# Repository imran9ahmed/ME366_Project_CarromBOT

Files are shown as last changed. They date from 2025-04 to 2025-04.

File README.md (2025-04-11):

# 🤖 Project Carrom Bot

## 📄 Abstract
An Arduino-based electro-mechanical robotic system designed to **automate the sorting of carrom pucks** using a **4-DOF robotic arm mounted on a mobile cart** with suction mechanism. The robot successfully demonstrates accurate puck picking and placement through pre-programmed logic. It showcases how low-cost electro-mechanical integration can be applied in precision automation tasks, with potential for scaling to industrial sorting systems.

> 🚀 Developed as part of the course [ME366: Electro-Mechanical System Design and Practice] at **Bangladesh University of Engineering and Technology (BUET)**.

---

## 📽️ Project Demonstrations

- 🎯 **Complete Project Demonstration**: [Watch on YouTube](https://www.youtube.com/watch?v=0QuMNoEQiSg)
- 🧲 **Suction Mechanism Tutorial**: [Watch Tutorial](https://www.youtube.com/watch?v=8Wvk7AqxIFw)

---

## 🧠 Objective

To design and implement a robotic system capable of autonomously arranging carrom discs into pre-programmed patterns with high accuracy and repeatability.

---

## 🛠️ Components Used

- Arduino Uno
- MG996R 10kg Servo Motors (×4)
- Nema-17 Stepper Motors (×2)
- DRV8825 Stepper Motor Driver
- L298N Motor Driver
- 12V DC Vacuum Pump
- Suction Cup with Vulcanized Rubber Tip
- Jumper & Electrical Wires
- DC-DC Buck Converter (LM2596)
- 85mm Plastic Wheels
- Custom Wooden and 3D Printed Chassis

---

## 🧩 How It Works

1. Stepper motor moves the bot to the center of the carrom board.
2. Servo motors manipulate the robotic arm to reach a disc.
3. Vacuum pump turns ON to pick up the disc.
4. The arm carries the disc to the target position.
5. Vacuum turns OFF to release it.
6. The bot moves backward to start the next sequence.
7. Repeats the process for all discs.

---

## 🧪 Methodology

- **CAD Design**: SolidWorks for modeling the cart and arm.
- **Fabrication**: Lightweight wooden body and polymer arms (3D printed).
- **Control**: Arduino IDE with pre-programmed sequences for each disc.
- **Motion**: 
  - Stepper motors drive the wheels (for mobility).
  - Servo motors control arm segments (for picking & placing).
  - Vacuum pump uses DC motor to hold discs during transport.

---

## 📊 Results

The robot successfully completed the task of picking and placing all carrom discs in the desired pattern during a live demonstration. The suction mechanism was robust, and servo positioning was accurate.

---

## 🖼️ Project Poster

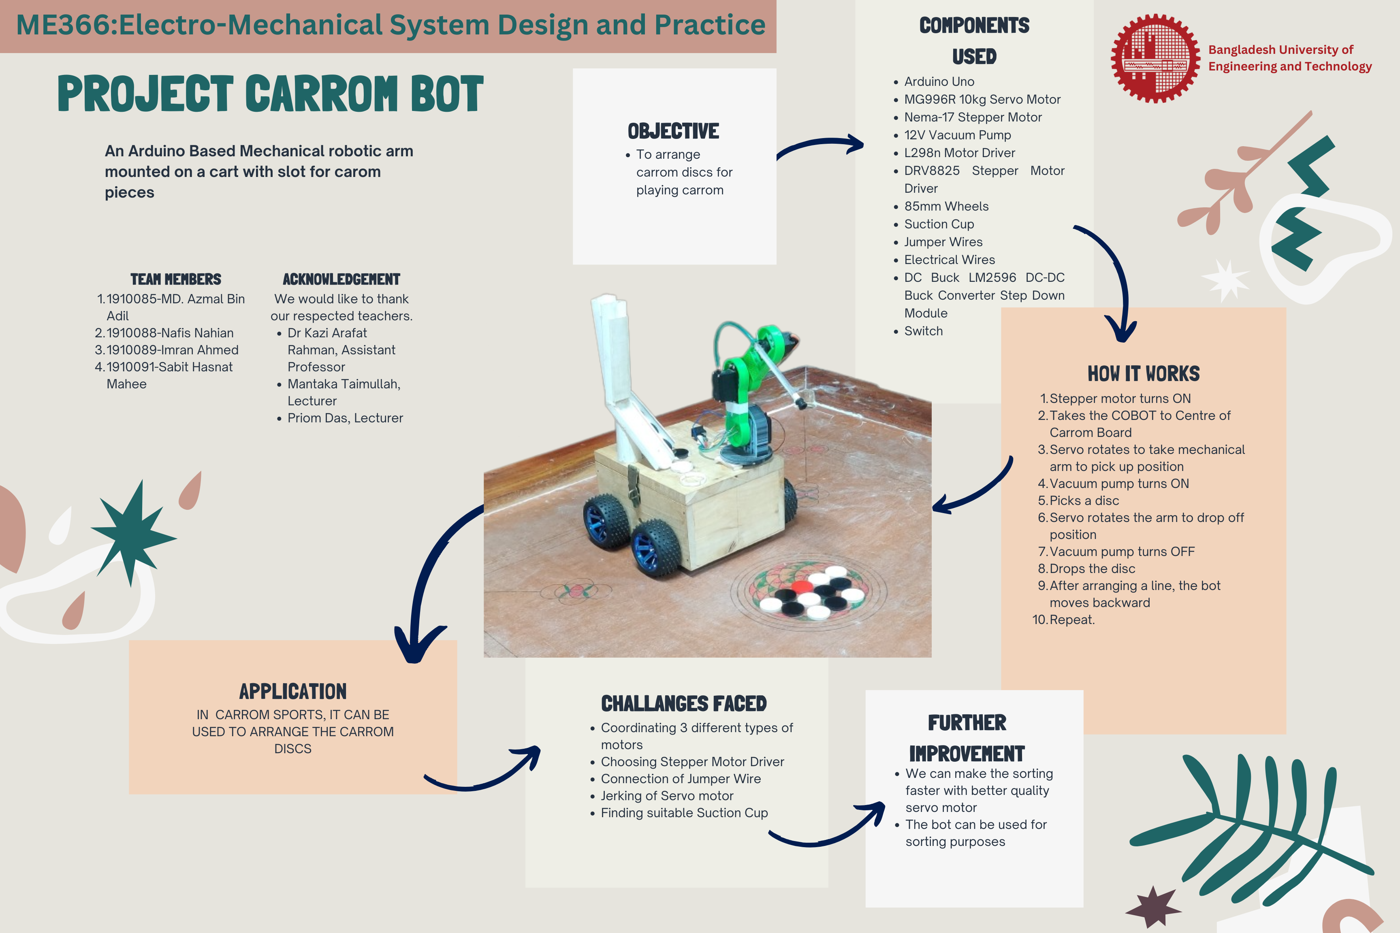
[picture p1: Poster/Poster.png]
Project Poster


---

## 📸 Project Showcase

**Bot on Field**
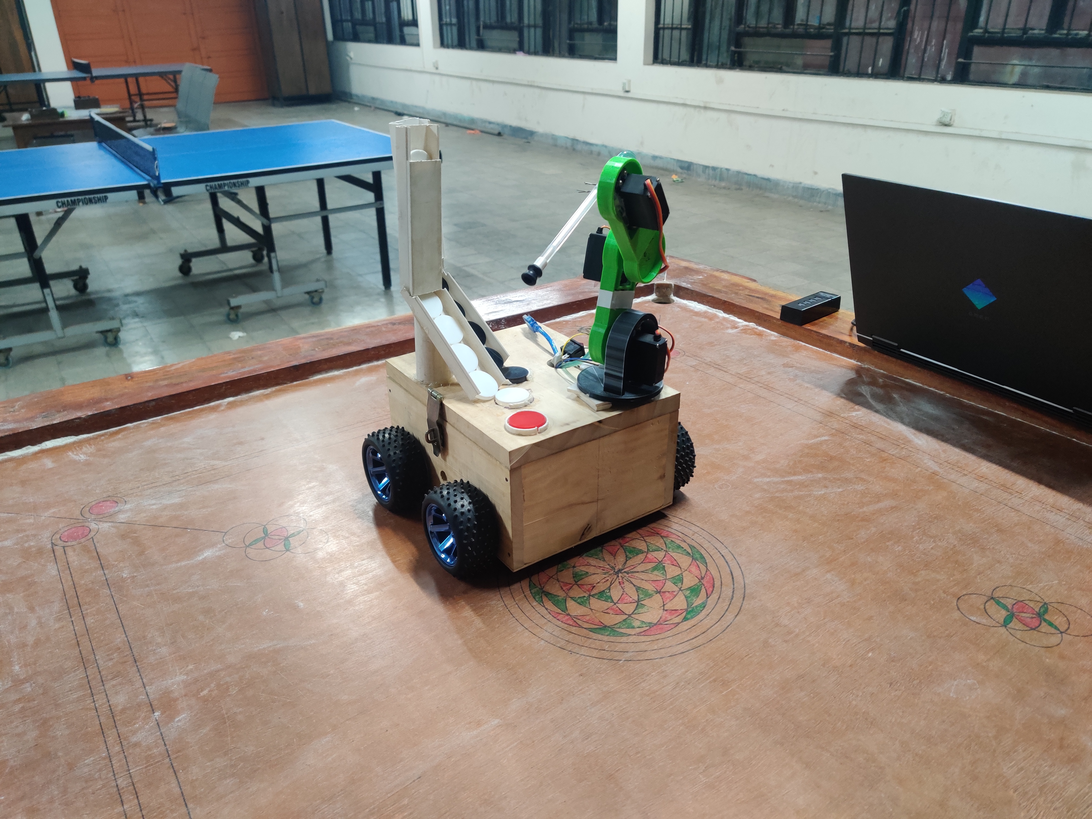
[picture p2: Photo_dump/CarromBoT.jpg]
CarromBot on Carrom Board


**Team at Exhibition**
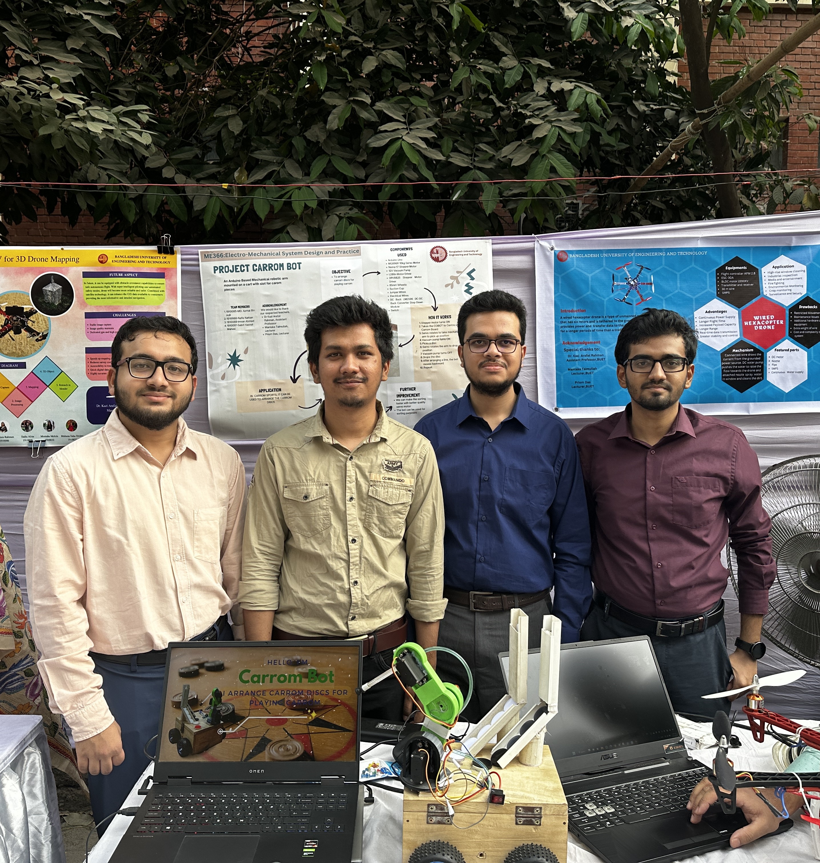
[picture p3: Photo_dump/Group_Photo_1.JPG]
Group Photo

---

## 🧠 Challenges Faced

- Coordinating 3 different types of motors (servo, stepper, DC)
- Power management and avoiding leakage
- Servo gear slippage during extended use
- Finding a suitable suction cup that provides a good seal
- Frequent recalibration due to mechanical tolerance issues

---

## 🛠️ Future Improvements

- Enhance sorting speed with industrial-grade servo motors
- Introduce **machine learning** to dynamically identify and recreate new patterns
- Upgrade arm design for improved mechanical accuracy and repeatability

---

## 📂 Files Included

- `Poster.png`: Visual overview of the project
- `ProjectCarromBot.pdf`: Full project report with design methodology, components, and results
- `code.ino`: Arduino source code with servo and motor control logic

---

## 👥 Team Members

- **MD. Azmal Bin Adil** (1910085)
- **Nafis Nahian** (1910088)
- **Imran Ahmed** (1910089)
- **Sabit Hasnat Mahee** (1910091)

---

## 📘 Citation

> Project Carrom Bot: An autonomous precision sorting robot prototype  
> [DOI: 10.13140/RG.2.2.15504.42249/2](https://www.researchgate.net/publication/384443774)

---

## 🏫 Department of Mechanical Engineering  
Bangladesh University of Engineering and Technology (BUET)

---

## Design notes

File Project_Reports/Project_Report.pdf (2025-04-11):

See discussions, stats, and author profiles for this publication at: https://www.researchgate.net/publication/384443774
Project Carrom Bot: An autonomous precision sorting robot prototype (https://www.researchgate.net/publication/384443774_Project_Carrom_Bot_An_autonomous_precision_sorting_robot_prototype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)

Technical Report · February 2020

DOI: 10.13140/RG.2.2.15504.42249/2

CITATIONS
0

READS
32

### 4 authors:

Sabit Hasnat Mahee (https://www.researchgate.net/profile/Sabit-Hasnat-Mahee?el=1_x_5&_esc=publicationCoverPdf)
Bangladesh University of Engineering and Technology (https://www.researchgate.net/institution/Bangladesh-University-of-Engineering-and-Technology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)

### 2 PUBLICATIONS 0 CITATIONS

SEE PROFILE (https://www.researchgate.net/profile/Sabit-Hasnat-Mahee?el=1_x_7&_esc=publicationCoverPdf)

Md. Azmal Bin Adil (https://www.researchgate.net/profile/Md-Azmal-Bin-Adil?el=1_x_5&_esc=publicationCoverPdf)
Bangladesh University of Engineering and Technology (https://www.researchgate.net/institution/Bangladesh-University-of-Engineering-and-Technology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)

### 3 PUBLICATIONS 0 CITATIONS

SEE PROFILE (https://www.researchgate.net/profile/Md-Azmal-Bin-Adil?el=1_x_7&_esc=publicationCoverPdf)

Imran Ahmed (https://www.researchgate.net/profile/Imran-Ahmed-78?el=1_x_5&_esc=publicationCoverPdf)
Bangladesh University of Engineering and Technology (https://www.researchgate.net/institution/Bangladesh-University-of-Engineering-and-Technology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)

### 1 PUBLICATION 0 CITATIONS

SEE PROFILE (https://www.researchgate.net/profile/Imran-Ahmed-78?el=1_x_7&_esc=publicationCoverPdf)

Nafis Nahian (https://www.researchgate.net/profile/Nafis-Nahian?el=1_x_5&_esc=publicationCoverPdf)
Bangladesh University of Engineering and Technology (https://www.researchgate.net/institution/Bangladesh-University-of-Engineering-and-Technology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)

### 1 PUBLICATION 0 CITATIONS

SEE PROFILE (https://www.researchgate.net/profile/Nafis-Nahian?el=1_x_7&_esc=publicationCoverPdf)

All content following this page was uploaded by Md. Azmal Bin Adil (https://www.researchgate.net/profile/Md-Azmal-Bin-Adil?el=1_x_10&_esc=publicationCoverPdf) on 23 October 2024.

The user has requested enhancement of the downloaded file.

## Bangladesh University of Engineering and Technology

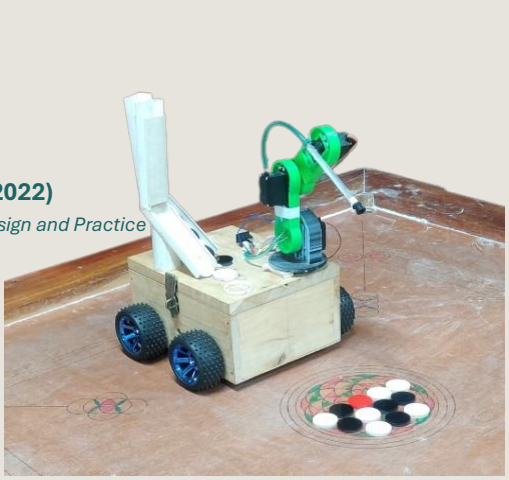
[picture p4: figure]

# cart with slot for carom pieces

## Group Members:

## 1. 1910091-Sabit Hasnat Mahee

## 2. 1910085-MD. Azmal Bin Adil

## 3. 1910089-Imran Ahmed

## 4. 1910088-Nafis Nahian

# Course: ME 366 (JUNE 2022)

## Electro-Mechanical System Design and Practice

# PROJECT CARROM BOT

# An Arduino Based Mechanical robotic arm mounted on a

Table of Contents

### Abstract

As part of our academic curriculum, we undertook a project focused on the design and development of an electro-mechanical system. Our chosen project was a four-degrees-of-freedom robotic arm with a suction mechanism, designed to sort carrom pucks. The primary objective was to create a fully automated robotic system capable of sorting objects in any pattern based on pre-programmed instructions. The system incorporated various electronic components such as an Arduino UNO, motor drivers, stepper motor, servo motor, vacuum pump, and suction tip. We used Arduino IDE as the software platform for this project. This bot can be applied to tasks involving sorting or pattern formation.

### Acknowledgements

We would like to express our sincere gratitude to everyone who contributed to the success of this project.

First and foremost, we are deeply grateful to our course teachers for their invaluable guidance, insightful suggestions, and continuous support throughout the development of this project. Their expertise and encouragement have been crucial in helping us navigate challenges and refine our work.

We would also like to extend our thanks to the Department of Mechanical Engineering at BUET for providing us with the resources and infrastructure necessary to complete this project. We appreciate the assistance from our faculty members, whose feedback helped us improve our understanding of key concepts.

### Introduction

In today's rapidly evolving world of automation and robotics, electro-mechanical systems play a crucial role in various industries. Our project, undertaken as part of the junior year academic curriculum, focuses on the design and development of a four-degrees-of-freedom robotic arm equipped with a suction mechanism. This robotic system is designed to sort carrom pucks into various predefined patterns, offering a real-world application of sorting and pattern formation through automation.

The primary objective of this project is to create a fully automated robotic arm capable of performing sorting tasks autonomously. By utilizing advanced control mechanisms and pre-programmed instructions, the robotic arm will be able to precisely pick, place, and organize carrom pucks. This system integrates a variety of electronic components, including an Arduino UNO as the microcontroller, motor drivers, stepper motors, servo motors, and a vacuum pump with a suction tip to effectively handle the objects.

The development of this project involves both hardware assembly and software programming, with the control logic being developed on the Arduino IDE platform. The versatile nature of the robotic arm allows it to be applied to a wide range of sorting and pattern-making tasks, beyond the sorting of carrom pucks. Applications in industrial automation, logistics, and warehouse management are just a few areas where such systems can improve efficiency and accuracy in organizing objects.

This project explores core concepts in robotics, automation, and control systems, aiming to demonstrate how these technologies can be used to solve practical problems in real-world scenarios.

### Methodology

The project is based on multiple stage of software and hardware development.

Structure Design
The Cobot model is primarily designed on SolidWorks
and then modified further as the project continues. It has two sections- 1) moving car base and 2) 4DOF arm. The arm sections are made of polymer using 3D printing of the model, and the car body is made from wood for light and rigid structure. It has 4 plastic wheels with rubber grip.

Components Used
- Arduino Uno
- MG996R Servo Motor
- Nema-17 Stepper Motor
- 12V DC Vacuum Pump
- L298n Motor Driver
- DRV8825 Motor Driver
- 85mm Wheels
- Suction Cup

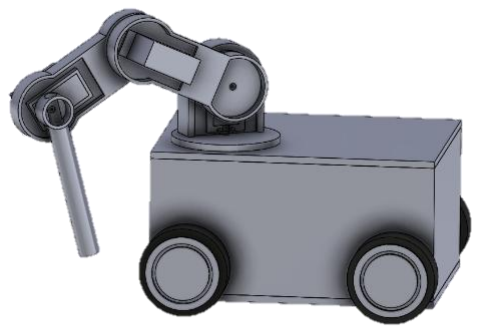
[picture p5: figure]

Figure: CAD model

Mechanism
The arm sections of robot move using 4 servo motor which are controlled by preprogrammed Arduino Uno microcontroller. The arm set up allows us a 4 DOF (degree of freedom) movement. Two of the four wheels driven by Nema-17 Stepper motor controlled by DRV8825 motor driver and the other two wheels are idle. A 12V DC motor runs the vacuum system which is controlled by L298n Motor driver. Vulcanized rubber tip is used for durability.

Software Programming
All motor movement is initially programmed in Arduino IDE and loaded to the Arduino UNO attached to the bot. Total task is executed in a single run and so every step of the robot is preprogrammed. For every carrom puck, the position of 4 servo motor is unique.

### Results

The robot runs accurately and places all the carrom pucks accordingly. The project is demonstrated to faculty members and other audience during a project exhibition organized by the Department of Mechanical Engineering at Bangladesh University of Engineering and Technology. To watch the demonstration video Click Here. (https://youtu.be/Lxy4_hEPyTA)

A video tutorial of the suction mechanism used in the project is also made. To watch “How to make suction probe” Click Here. (https://youtu.be/Ve732q9mDFg)

### Discussion

Developing a robot for such precise a job from scratch was indeed a difficult task. The first challenge we faced was coordinating the servo motors, stepper motors, and the dc motor present in the vacuum pump. As the motors run at different power ratings and use different types of drivers, power leakage caused unwanted starting and stopping of the motors. Upon solving this vary problem we faced gear slippage in the servo motors which persisted till the end of the project. Due to this reason, picking and placing of pucks had to be calibrated frequently.

As this robot was employed to create a known pattern instructions regarding the exact locations of sorting the pucks were given directly. For further advancement machine learning can be introduced in this. As a result, the robot will be able to read any pattern it is shown and recreate that on its own.

View publication stats (https://www.researchgate.net/publication/384443774)

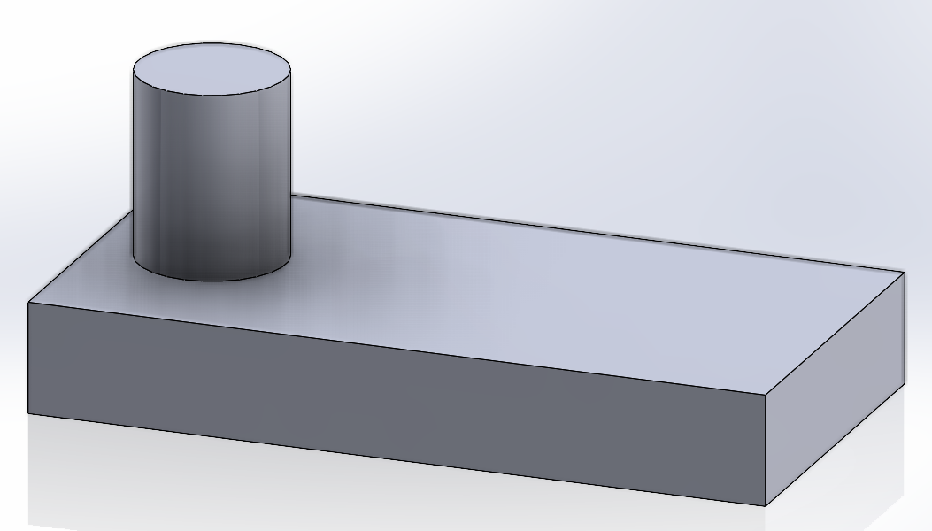
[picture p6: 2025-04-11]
SOLIDWORKS/Photos/Hand_Tip.png

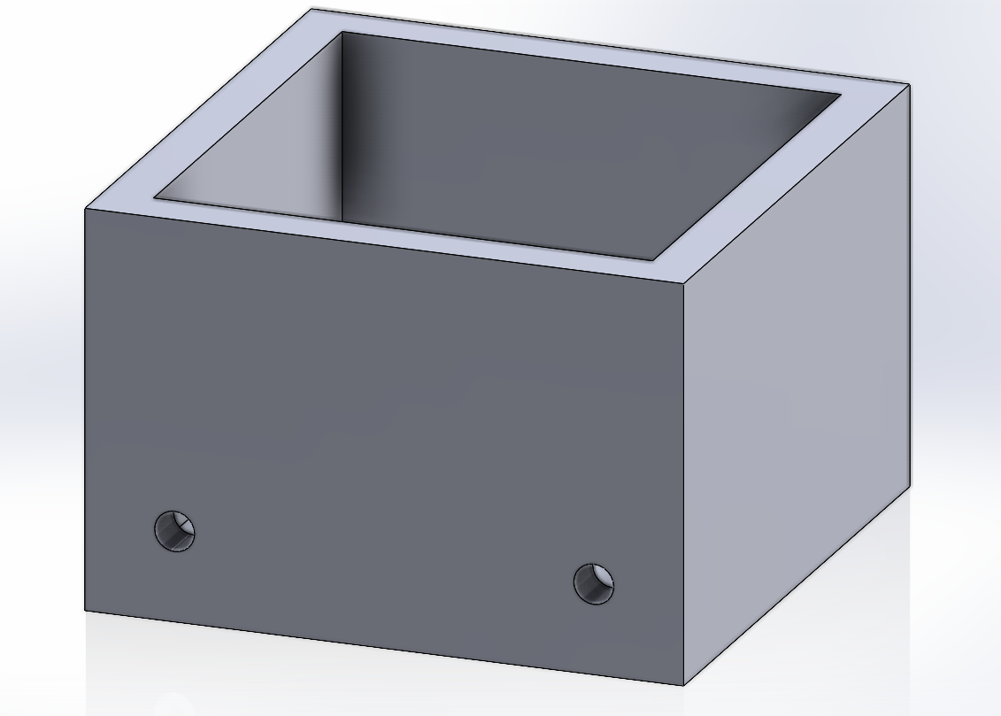
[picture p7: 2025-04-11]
SOLIDWORKS/Photos/Body.png

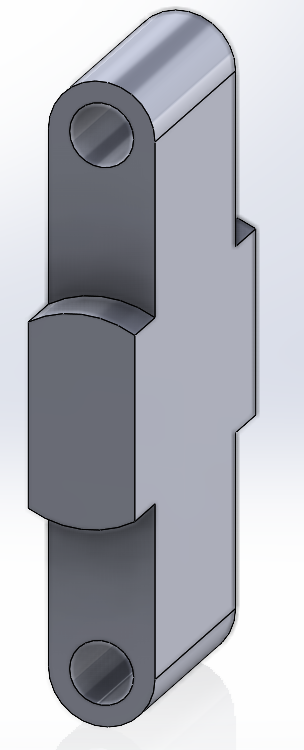
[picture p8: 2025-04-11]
SOLIDWORKS/Photos/Hand_Mid.png

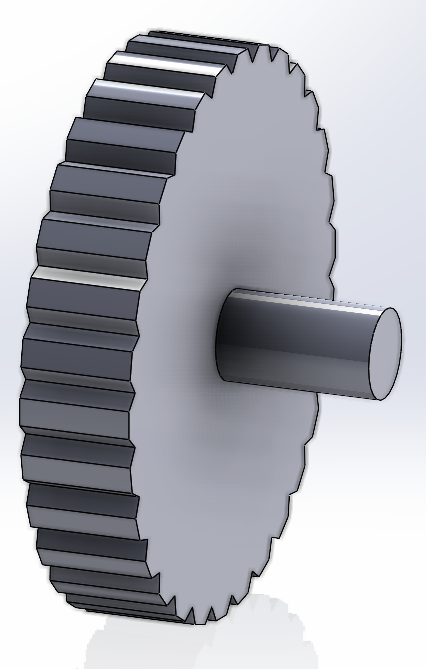
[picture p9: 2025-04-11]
SOLIDWORKS/Photos/Wheel.png

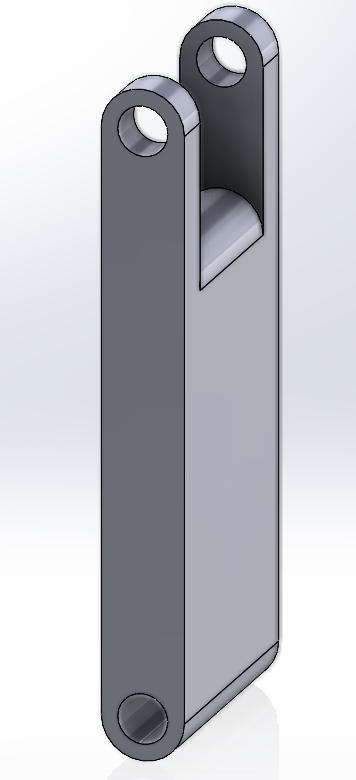
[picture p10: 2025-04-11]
SOLIDWORKS/Photos/Hand_Base_1.png

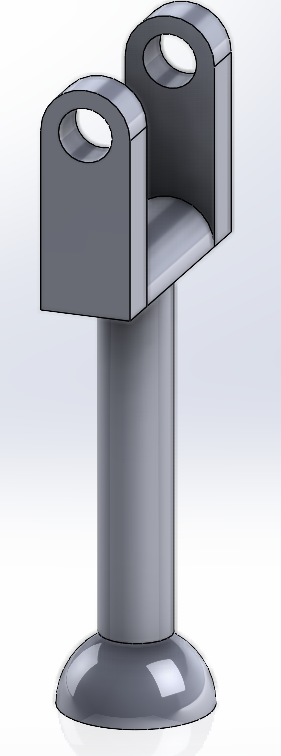
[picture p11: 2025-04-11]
SOLIDWORKS/Photos/Hand_Base_2.png

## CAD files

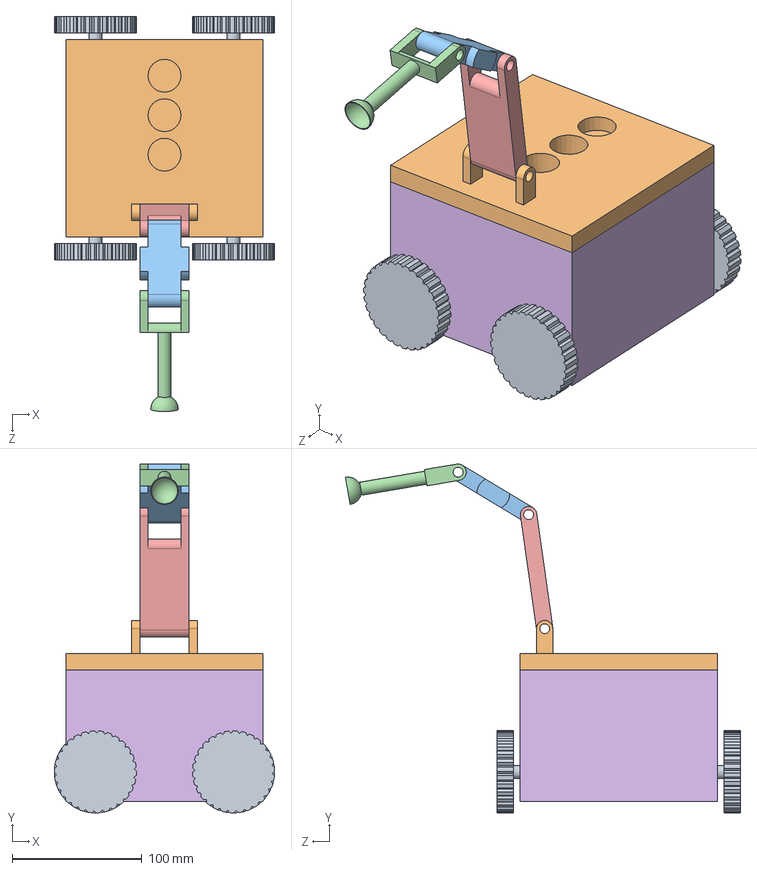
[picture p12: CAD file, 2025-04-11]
SOLIDWORKS/3D_models/Assemembly.SLDASM
170.2 x 269.4 x 304.9 mm
Hand Base
Hand Base - Copy
Hand mid
Lid
Wheel x 4

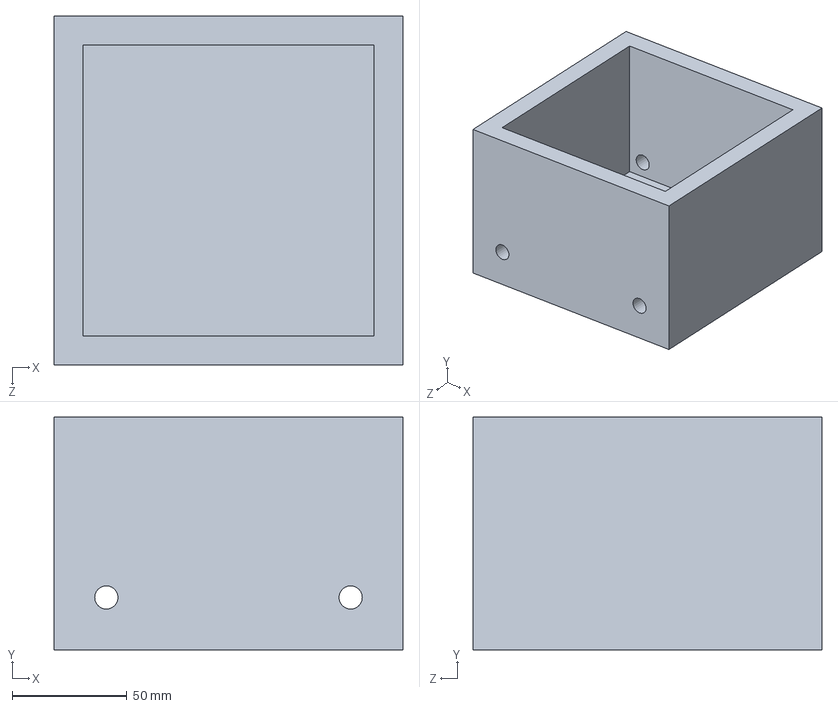
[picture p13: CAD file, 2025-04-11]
SOLIDWORKS/3D_models/Body.SLDPRT
152.4 x 101.6 x 152.4 mm

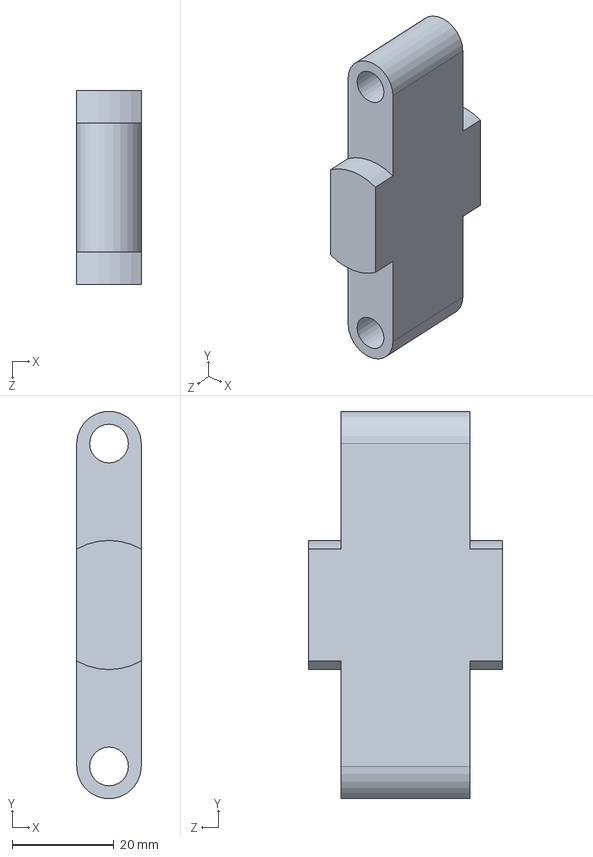
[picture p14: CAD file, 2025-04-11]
SOLIDWORKS/3D_models/Hand mid.SLDPRT
12.7 x 76.1 x 38.1 mm

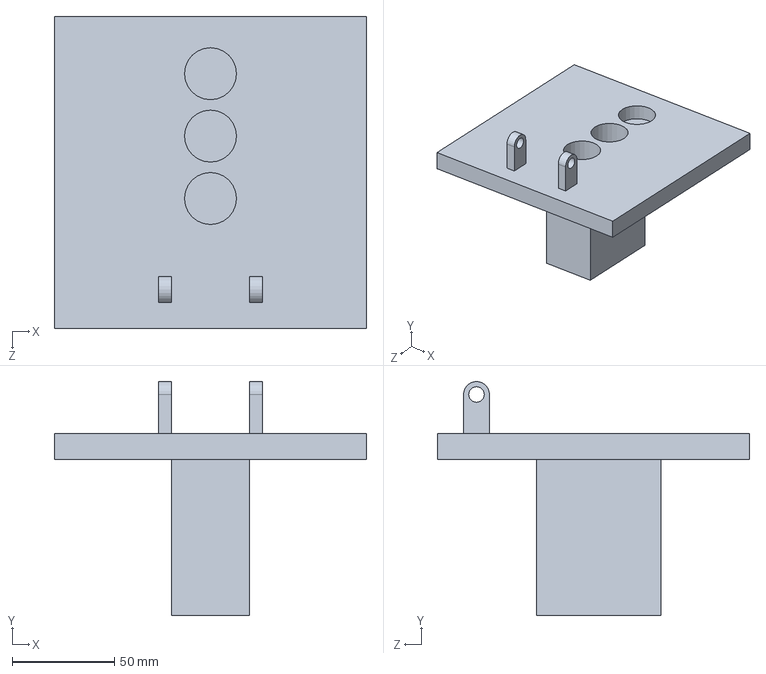
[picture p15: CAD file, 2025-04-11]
SOLIDWORKS/3D_models/Lid.SLDPRT
152.4 x 114.3 x 152.4 mm

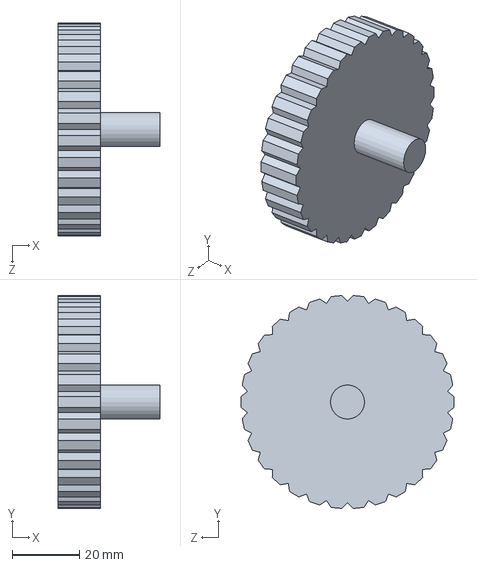
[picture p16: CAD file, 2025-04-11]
SOLIDWORKS/3D_models/Wheel.SLDPRT
30.5 x 63.4 x 63.4 mm

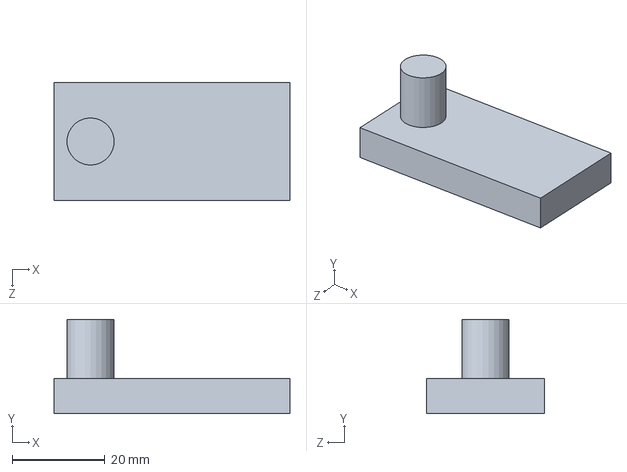
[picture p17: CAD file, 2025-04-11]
SOLIDWORKS/3D_models/Hand Tip.SLDPRT
50.8 x 20.3 x 25.4 mm

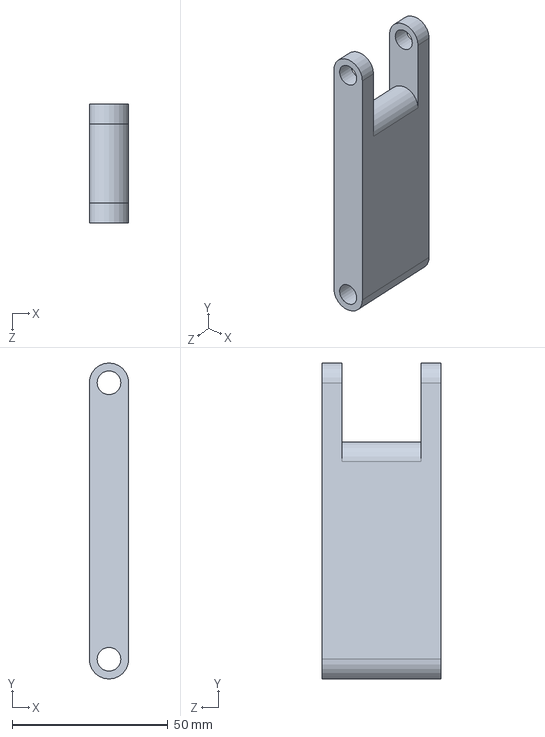
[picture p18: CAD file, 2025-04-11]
SOLIDWORKS/3D_models/Hand Base.SLDPRT
12.7 x 101.6 x 38.1 mm

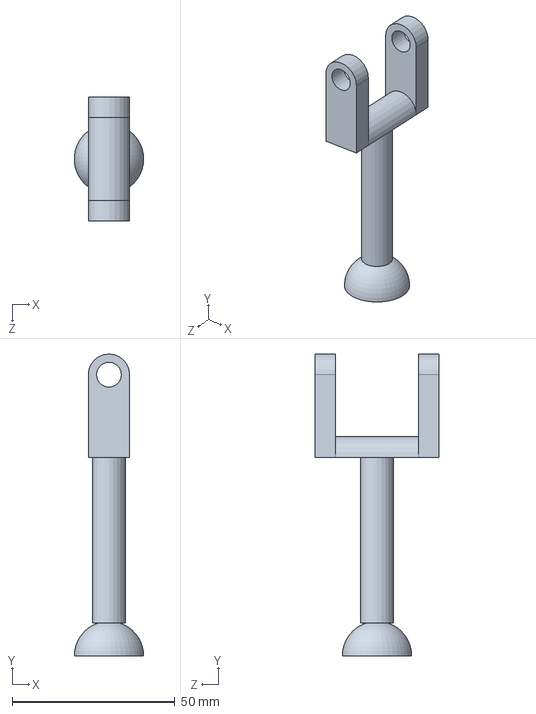
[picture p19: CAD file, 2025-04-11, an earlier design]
SOLIDWORKS/3D_models/Hand Base - Copy.SLDPRT
21.3 x 92.7 x 38.1 mm

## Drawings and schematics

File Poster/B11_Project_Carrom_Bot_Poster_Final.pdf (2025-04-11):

## COMPONENTS USED

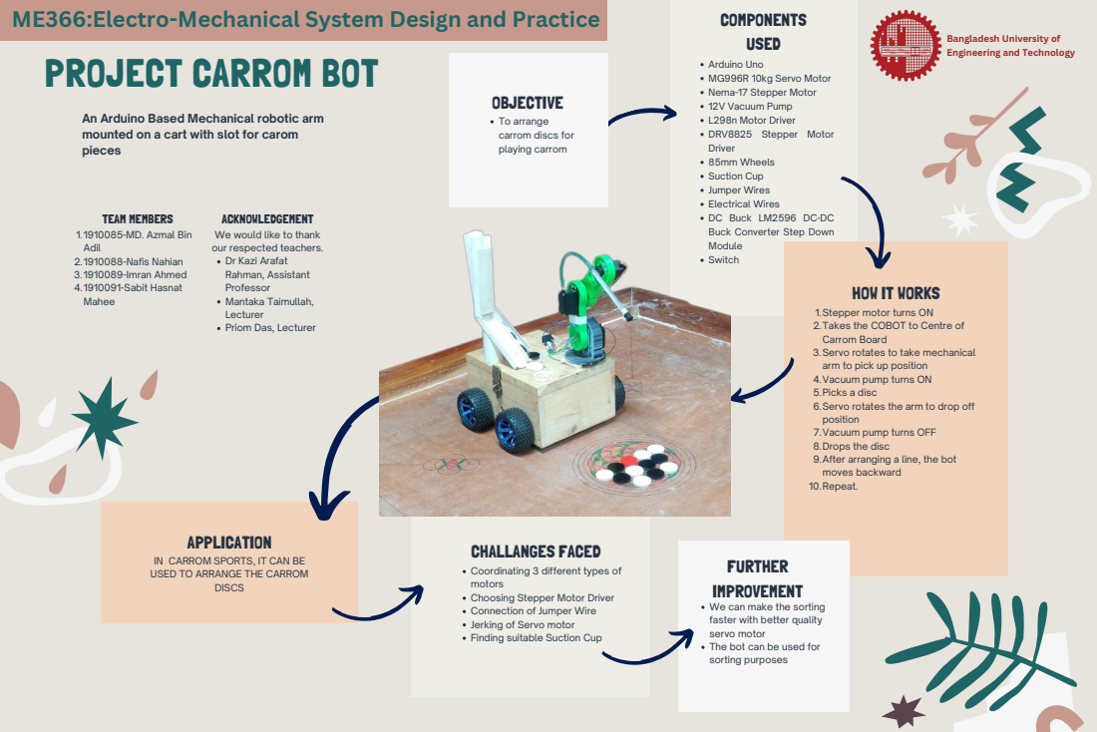
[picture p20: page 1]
APPLICATION; DISCS; RELATED LITERATURE; OBJECTIVE; CHALLANGES FACED

ME366:Electro-Mechanical System Design and Practice
PROJECT CARROM BOT

Bangladesh University of
Engineering and Technology

Arduino Uno
MG996R 10kg Servo Motor
Nema-17 Stepper Motor
12V Vacuum Pump
L298n Motor Driver
DRV8825 Stepper Motor
Driver
85mm Wheels
Suction Cup
Jumper Wires
Electrical Wires
DC Buck LM2596 DC-DC
Buck Converter Step Down
Module
Switch

An Arduino Based Mechanical robotic arm
mounted on a cart with slot for carom
pieces

To arrange
carrom discs for
playing carrom

TEAM MEMBERS
1910085-MD. Azmal Bin
Adil
1910088-Nafis Nahian
1910089-Imran Ahmed
1910091-Sabit Hasnat
Mahee

ACKNOWLEDGEMENT
We would like to thank
our respected teachers.
Dr Kazi Arafat
Rahman, Assistant
Professor
Mantaka Taimullah,
Lecturer
Priom Das, Lecturer

HOW IT WORKS

Stepper motor turns ON
Takes the COBOT to Centre of
Carrom Board
Servo rotates to take mechanical
arm to pick up position
Vacuum pump turns ON
Picks a disc
Servo rotates the arm to drop off
position
Vacuum pump turns OFF
Drops the disc
After arranging a line, the bot
moves backward
Repeat.

IN CARROM SPORTS, IT CAN BE
USED TO ARRANGE THE CARROM

FURTHER
IMPROVEMENT
We can make the sorting
faster with better quality
servo motor
The bot can be used for
sorting purposes

Coordinating 3 different types of
motors
Choosing Stepper Motor Driver
Connection of Jumper Wire
Jerking of Servo motor
Finding suitable Suction Cup

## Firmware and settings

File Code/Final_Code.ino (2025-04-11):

#include <AccelStepper.h>
#include <Servo.h>
const int dirPin = 26;
const int stepPin = 3;
Servo myservo1; 
Servo myservo2; 
Servo myservo3; 
Servo myservo4; // create servo object to control a servo
int pos=0 ;// variable to store the servo position
int in1 = 9; //Declaring the pins where in1 in2 from the driver are wired 
int in2 = 46; //here they are wired with D9 and D46 from Arduino
#define motorInterfaceType 1 // Creates an instance
AccelStepper myStepper(motorInterfaceType, stepPin, dirPin);
void TurnMotorA(){              
  digitalWrite(in1, HIGH);
  digitalWrite(in2, LOW);
}                         // Defining function to turn on the vacuum pump

void TurnOFFA(){
  digitalWrite(in1, LOW);
  digitalWrite(in2, LOW);
}                        // Defining function to turn off the vacuum pump
void PickWhite(){
  myservo1.write(30);
  myservo4.write(59); 
  myservo2.write(85); 
  for (pos = 90; pos <= 150; pos += 1) { 
    myservo3.write(pos); 
    delay(20);           
  }
  delay(1000);
  TurnMotorA();
  for (pos = 85; pos >= 70; pos -= 1) { 
    myservo2.write(pos); 
    delay(20);            
  }
  delay(1000);  
  for (pos = 70; pos <= 90; pos += 1) { 
    myservo2.write(pos); 
    delay(20);            
  }
}                      // Defining function to pic white disc
void PickBlack(){
  myservo2.write(100);
  myservo1.write(0);
  myservo4.write(68); 
  for (pos = 90; pos <= 155; pos += 1) { 
    myservo3.write(pos); 
    delay(20);            
  }
  for (pos = 100; pos >= 90; pos -= 1) { 
    myservo2.write(pos); 
    delay(20);             
  }
  delay(1000);
  TurnMotorA();
  for (pos = 90; pos >= 70; pos -= 1) { 
    myservo2.write(pos); 
    delay(20);             
  }
  delay(1000);
  
  for (pos = 70; pos <= 80; pos += 1) { 
    myservo2.write(pos); 
    delay(20);            
  }
  for (pos = 80; pos <= 100; pos += 1) { 
    myservo2.write(pos); 
    delay(20);            
  }
}                      // Defining function to pic white disc
void setup() {
  pinMode(in1, OUTPUT); //Declaring the pin modes, obviously they're outputs
  pinMode(in2, OUTPUT);
  myStepper.setMaxSpeed(1000);
	myStepper.setAcceleration(50);
	myStepper.setSpeed(200);
  myservo1.attach(5); // Declaring pins to attach Servos
  myservo2.attach(6);
  myservo3.attach(10);
  myservo4.attach(11);
  myservo1.write(150); // Declaring initial positions of servos
  myservo2.write(90); 
  myservo3.write(90);  
  myservo4.write(45);
  myStepper.moveTo(-218);
  myStepper.runToPosition();
  TurnMotorA();
  delay(1000);
  TurnOFFA();
  Serial.begin(9600); // Bot is at a distance of 5.5 cm from the center
  // Initiates picking sequence for disc 1
  PickWhite();
  // Completes picking the disc and initiates dropping sequence
  for (pos = 150; pos >= 120; pos -= 1) { 
    myservo3.write(pos); 
    delay(20);            
  }
  for (pos = 30; pos <= 146; pos += 1) { 
    myservo1.write(pos);
    delay(20);             
  } 
  for (pos = 90; pos >= 75; pos -= 1) {
    myservo2.write(pos); 
    delay(20);            
  }
  for (pos = 120; pos >= 80; pos -= 1) { 
    myservo3.write(pos);
    delay(20);             
  }
  for (pos =60; pos <=86; pos += 1) { 
    myservo4.write(pos); 
    delay(20);             
  }
  for (pos = 75; pos >= 0; pos -= 1) { 
    myservo2.write(pos); 
    delay(20);            
  }
  TurnOFFA();
  // Drops disc 1  
  delay(1000);
  // Initiates picking sequence for disc 2
  for (pos = 0; pos <= 90; pos += 1) { 
    myservo2.write(pos); 
    delay(20);            
  }
  myservo4.write(45);
  myservo1.write(150);
  PickBlack();
  // Completes picking the disc and initiates dropping sequence
  for (pos = 150; pos >= 120; pos -= 1) { 
    myservo3.write(pos); 
    delay(20);             
  }
  for (pos = 100; pos <= 120; pos += 1) { 
    myservo2.write(pos); 
    delay(20);            
  }
  for (pos = 0; pos <= 132; pos += 1) {
    myservo1.write(pos);
    delay(20);             
  }
  for (pos = 120; pos >= 75; pos -= 1) { 
    myservo2.write(pos); 
    delay(20);             
  }
  for (pos = 120; pos >= 80; pos -= 1) { 
    myservo3.write(pos);
    delay(20);              
  } 
  for (pos =60; pos <=90; pos += 1) { 
    myservo4.write(pos); 
    delay(20);             
  }
  for (pos = 75; pos >= 0; pos -= 1) { 
    myservo2.write(pos); 
    delay(20);            
  }
  TurnOFFA();
  // Drops disc 2
  delay(1000);
  // Initiates picking sequence for disc 3
  for (pos = 0; pos <= 90; pos += 1) { 
    myservo2.write(pos); 
    delay(20);            
  }
  myservo4.write(45);
  myservo1.write(150);
  PickWhite();
  // Completes picking the disc and initiates dropping sequence
  for (pos = 150; pos >= 120; pos -= 1) { 
    myservo3.write(pos); 
    delay(20);             
  }
  for (pos = 30; pos <= 121; pos += 1) { 
    myservo1.write(pos);
    delay(20);              
  }
  for (pos = 90; pos >= 75; pos -= 1) {
    myservo2.write(pos); 
    delay(20);           
  }
  for (pos = 120; pos >= 80; pos -= 1) { 
    myservo3.write(pos);
    delay(20);             
  }
  for (pos =60; pos <=96; pos += 1) { 
    myservo4.write(pos); 
    delay(20);             
  }
  for (pos = 75; pos >= 0; pos -= 1) { 
    myservo2.write(pos); 
    delay(20);             
  }
  TurnOFFA();
  // Drops disc 3
  delay(1000);
  // Initiates picking sequence for disc 4
  for (pos = 0; pos <= 90; pos += 1) { 
    myservo2.write(pos); 
    delay(20);            
  }
  myservo4.write(45);
  myservo1.write(150);
  // Move the bot backwards by 0.5 cm
  myStepper.moveTo(-211);
  myStepper.runToPosition();
  PickBlack();
  // Completes picking the disc and initiates dropping sequence
  for (pos = 150; pos >= 120; pos -= 1) { 
    myservo3.write(pos); 
    delay(20);            
  }
  for (pos = 100; pos <= 120; pos += 1) { 
    myservo2.write(pos); 
    delay(20);            
  }
  for (pos = 0; pos <= 150; pos += 1) {
    myservo1.write(pos);
    delay(20);              
  }
  for (pos = 120; pos >= 75; pos -= 1) { 
    myservo2.write(pos); 
    delay(20);            
  }
  for (pos = 120; pos >= 110; pos -= 1) { 
    myservo3.write(pos);
    delay(20);              
  }
  for (pos =60; pos <=105; pos += 1) { 
    myservo4.write(pos); 
    delay(20);            
  }
  for (pos = 75; pos >= 0; pos -= 1) { 
    myservo2.write(pos); 
    delay(20);             
  }
  TurnOFFA();
  // Drops disc 4
  delay(1000);
  // Initiates picking sequence for disc 5
  for (pos = 0; pos <= 90; pos += 1) { 
    myservo2.write(pos); 
    delay(20);            
  }
  myservo4.write(45);
  myservo1.write(150);
  PickBlack();
  // Completes picking the disc and initiates dropping sequence
  for (pos = 150; pos >= 120; pos -= 1) { 
    myservo3.write(pos); 
    delay(20);             
  }
  for (pos = 100; pos <= 120; pos += 1) { 
    myservo2.write(pos); 
    delay(20);            
  }
   for (pos = 0; pos <= 134; pos += 1) { 
    myservo1.write(pos);
    delay(20);              
  }
  for (pos = 120; pos >= 75; pos -= 1) { 
    myservo2.write(pos); 
    delay(20);             
  }
  for (pos = 120; pos >= 110; pos -= 1) { 
    myservo3.write(pos);
    delay(20);             
  }
  for (pos =60; pos <=107; pos += 1) {
    myservo4.write(pos); 
    delay(20);            
  }
  for (pos = 75; pos >= 0; pos -= 1) { 
    myservo2.write(pos); 
    delay(20);             
  }
  TurnOFFA();
  // Drops Disc 5
  delay(1000);
  // Initiates picking sequence for disc 6
  for (pos = 0; pos <= 90; pos += 1) { 
    myservo2.write(pos); 
    delay(20);            
  }
  myservo4.write(45);
  myservo1.write(150);
  PickWhite();
  // Completes picking the disc and initiates dropping sequence
  for (pos = 150; pos >= 120; pos -= 1) { 
    myservo3.write(pos); 
    delay(20);             
  }
  for (pos = 30; pos <= 122; pos += 1) { 
    myservo1.write(pos);
    delay(20);              
  }
  for (pos = 90; pos >= 75; pos -= 1) {
    myservo2.write(pos); 
    delay(20);           
  }
  for (pos = 120; pos >= 99; pos -= 1) { 
    myservo3.write(pos);
    delay(20);             
  }
  for (pos =60; pos <=102; pos += 1) { 
    myservo4.write(pos); 
    delay(20);             
  }
  for (pos = 75; pos >= 0; pos -= 1) { 
    myservo2.write(pos); 
    delay(20);             
  }
  TurnOFFA();
  // Drops disc 6
  delay(1000);
  // Initiates picking sequence for disc 7
  // Move the  bot backwards by 1 cm  
  for (pos = 0; pos <= 90; pos += 1) { 
    myservo2.write(pos); 
    delay(20);            
  }
  myservo4.write(45);
  myservo1.write(150);
  PickBlack();
  // Completes picking the disc and initiates dropping sequence
  for (pos = 150; pos >= 120; pos -= 1) { 
    myservo3.write(pos); 
    delay(20);             
  }
  for (pos = 100; pos <= 120; pos += 1) { 
    myservo2.write(pos); 
    delay(20);            
  }  
  for (pos = 30; pos <= 111; pos += 1) { 
    myservo1.write(pos);
    delay(20);              
  }
  for (pos = 120; pos >= 75; pos -= 1) {
    myservo2.write(pos); 
    delay(20);           
  }
  for (pos = 120; pos >= 100; pos -= 1) { 
    myservo3.write(pos);
    delay(20);             
  }
  for (pos =60; pos <=117; pos += 1) { 
    myservo4.write(pos); 
    delay(20);             
  }
  for (pos = 75; pos >= 0; pos -= 1) { 
    myservo2.write(pos); 
    delay(20);             
  }
  TurnOFFA();
  // Drops disc 7
  delay(1000);
  // Initiates picking sequence for disc 8
  for (pos = 0; pos <= 90; pos += 1) { 
    myservo2.write(pos); 
    delay(20);            
  }
  myservo4.write(45);
  myservo1.write(150);
  myStepper.moveTo(-203);
  myStepper.runToPosition();
  PickWhite();
  // Completes picking the disc and initiates dropping sequence
  for (pos = 150; pos >= 119; pos -= 1) { 
    myservo3.write(pos); 
    delay(20);            
  }
  for (pos = 30; pos <= 160; pos += 1) { 
    myservo1.write(pos);
    delay(20);             
  } 
  for (pos = 90; pos >= 75; pos -= 1) {
    myservo2.write(pos); 
    delay(20);            
  }
  for (pos = 120; pos >= 180; pos -= 1) { 
    myservo3.write(pos);
    delay(20);             
  }
  for (pos =60; pos <=90; pos += 1) { 
    myservo4.write(pos); 
    delay(20);             
  }
  for (pos = 75; pos >= 20; pos -= 1) { 
    myservo2.write(pos); 
    delay(20);            
  }
  TurnOFFA();
  // Drops disc 8
  delay(1000);   
  // Initiates picking sequence for disc 9
  for (pos = 20; pos <= 90; pos += 1) { 
    myservo2.write(pos); 
    delay(20);            
  }
  myservo4.write(45);
  myservo1.write(150);
  PickWhite();
  // Completes picking the disc and initiates dropping sequence
  for (pos = 150; pos >= 120; pos -= 1) { 
    myservo3.write(pos); 
    delay(20);            
  }
  for (pos = 30; pos <= 145; pos += 1) { 
    myservo1.write(pos);
    delay(20);             
  } 
  for (pos = 90; pos >= 75; pos -= 1) {
    myservo2.write(pos); 
    delay(20);            
  }
  for (pos = 120; pos >= 180; pos -= 1) { 
    myservo3.write(pos);
    delay(20);             
  }
  for (pos =60; pos <=93; pos += 1) { 
    myservo4.write(pos); 
    delay(20);             
  }
  for (pos = 75; pos >= 20; pos -= 1) { 
    myservo2.write(pos); 
    delay(20);            
  }
  TurnOFFA();
  // Drops disc 9
  delay(1000);   
  // Initiates picking sequence for disc 10
  for (pos = 20; pos <= 90; pos += 1) { 
    myservo2.write(pos); 
    delay(20);            
  }
  myservo4.write(45);
  myservo1.write(150);
  // Initiates picking sequence for disc 10
  myservo1.write(62);
  myservo4.write(62); 
  myservo2.write(85); 
  for (pos = 90; pos <= 150; pos += 1) { 
    myservo3.write(pos); 
    delay(20);           
  }
  delay(1000);
  TurnMotorA();
  for (pos = 85; pos >= 70; pos -= 1) { 
    myservo2.write(pos); 
    delay(20);            
  }
  delay(1000);  
  for (pos = 70; pos <= 90; pos += 1) { 
    myservo2.write(pos); 
    delay(20);            
  }
  // Completes picking the disc and initiates dropping sequence
  for (pos = 150; pos >= 120; pos -= 1) { 
    myservo3.write(pos); 
    delay(20);            
  }
  for (pos =60; pos <= 125; pos += 1) { 
    myservo1.write(pos);
    delay(20);             
  } 
  for (pos = 90; pos >= 75; pos -= 1) {
    myservo2.write(pos); 
    delay(20);            
  }
  for (pos = 120; pos >= 180; pos -= 1) { 
    myservo3.write(pos);
    delay(20);             
  }
  for (pos =60; pos <=93; pos += 1) { 
    myservo4.write(pos); 
    delay(20);             
  }
  for (pos = 75; pos >= 21; pos -= 1) { 
    myservo2.write(pos); 
    delay(20);            
  }
  TurnOFFA();
  // Drops disc 10
  delay(1000);  
  // Initiates picking sequence for disc 11
  for (pos = 21; pos <= 90; pos += 1) { 
    myservo2.write(pos); 
    delay(20);            
  }
  myservo4.write(45);
  myservo1.write(150);
  PickBlack();
  // Completes picking the disc and initiates dropping sequence
  for (pos = 150; pos >= 120; pos -= 1) { 
    myservo3.write(pos); 
    delay(20);            
  }
  for (pos = 100; pos <= 120; pos += 1) { 
    myservo2.write(pos); 
    delay(20);            
  }
  for (pos =0; pos <= 107; pos += 1) { 
    myservo1.write(pos);
    delay(20);             
  } 
  for (pos = 120; pos >= 75; pos -= 1) {
    myservo2.write(pos); 
    delay(20);            
  }
  for (pos = 120; pos >= 180; pos -= 1) { 
    myservo3.write(pos);
    delay(20);             
  }
  for (pos =60; pos <=104; pos += 1) { 
    myservo4.write(pos); 
    delay(20);             
  }
  for (pos = 75; pos >= 20; pos -= 1) { 
    myservo2.write(pos); 
    delay(20);            
  }
  TurnOFFA();
  // Drops disc 11
  delay(1000);   
  // Initiates picking sequence for disc 12
  for (pos = 21; pos <= 90; pos += 1) { 
    myservo2.write(pos); 
    delay(20);            
  }
  myservo4.write(45);
  myservo1.write(150);
  PickWhite();
  // Completes picking the disc and initiates dropping sequence
  for (pos = 150; pos >= 120; pos -= 1) { 
    myservo3.write(pos); 
    delay(20);            
  }
  for (pos =30; pos <= 101; pos += 1) { 
    myservo1.write(pos);
    delay(20);             
  } 
  for (pos = 90; pos >= 75; pos -= 1) {
    myservo2.write(pos); 
    delay(20);            
  }
  for (pos = 120; pos >= 180; pos -= 1) { 
    myservo3.write(pos);
    delay(20);             
  }
  for (pos =60; pos <=113; pos += 1) { 
    myservo4.write(pos); 
    delay(20);             
  }
  for (pos = 75; pos >= 20; pos -= 1) { 
    myservo2.write(pos); 
    delay(20);            
  }
  TurnOFFA();
  // Drops disc 12
  delay(1000);
  // Initiates picking sequence for disc 13
  for (pos = 21; pos <= 90; pos += 1) { 
    myservo2.write(pos); 
    delay(20);            
  }
  myservo4.write(45);
  myservo1.write(150);
  // Move the bot backwards by 5.5 cm
  myStepper.moveTo(-159);
  myStepper.runToPosition();
  PickBlack();
  // Completes picking the disc and initiates dropping sequence
  for (pos = 150; pos >= 120; pos -= 1) { 
    myservo3.write(pos); 
    delay(20);            
  }
  for (pos = 100; pos <= 120; pos += 1) { 
    myservo2.write(pos); 
    delay(20);            
  }
  for (pos = 0; pos <= 150; pos += 1) {
    myservo1.write(pos);
    delay(20);              
  }
  for (pos = 120; pos >= 75; pos -= 1) { 
    myservo2.write(pos); 
    delay(20);            
  }
  for (pos = 120; pos >= 110; pos -= 1) { 
    myservo3.write(pos);
    delay(20);              
  }
  for (pos =60; pos <=106; pos += 1) { 
    myservo4.write(pos); 
    delay(20);            
  }
  for (pos = 75; pos >= 0; pos -= 1) { 
    myservo2.write(pos); 
    delay(20);             
  }
  TurnOFFA();
  // Drops disc 13
  delay(1000);
  // Initiates picking sequence for disc 14
  for (pos = 0; pos <= 90; pos += 1) { 
    myservo2.write(pos); 
    delay(20);            
  }
  myservo4.write(45);
  myservo1.write(150);
  PickBlack();
  // Completes picking the disc and initiates dropping sequence
  for (pos = 150; pos >= 120; pos -= 1) { 
    myservo3.write(pos); 
    delay(20);             
  }
  for (pos = 100; pos <= 120; pos += 1) { 
    myservo2.write(pos); 
    delay(20);            
  }
   for (pos = 0; pos <= 134; pos += 1) { 
    myservo1.write(pos);
    delay(20);              
  }
  for (pos = 120; pos >= 75; pos -= 1) { 
    myservo2.write(pos); 
    delay(20);             
  }
  for (pos = 120; pos >= 110; pos -= 1) { 
    myservo3.write(pos);
    delay(20);             
  }
  for (pos =60; pos <=109; pos += 1) {
    myservo4.write(pos); 
    delay(20);            
  }
  for (pos = 75; pos >= 0; pos -= 1) { 
    myservo2.write(pos); 
    delay(20);             
  }
  TurnOFFA();
  // Drops Disc 5
  delay(1000);
  // Initiates picking sequence for disc 15
  for (pos = 0; pos <= 90; pos += 1) { 
    myservo2.write(pos); 
    delay(20);            
  }
  myservo4.write(45);
  myservo1.write(150);
  PickWhite();
  // Completes picking the disc and initiates dropping sequence
  for (pos = 150; pos >= 120; pos -= 1) { 
    myservo3.write(pos); 
    delay(20);             
  }
  for (pos = 30; pos <= 122; pos += 1) { 
    myservo1.write(pos);
    delay(20);              
  }
  for (pos = 90; pos >= 75; pos -= 1) {
    myservo2.write(pos); 
    delay(20);           
  }
  for (pos = 120; pos >= 99; pos -= 1) { 
    myservo3.write(pos);
    delay(20);             
  }
  for (pos =60; pos <=101; pos += 1) { 
    myservo4.write(pos); 
    delay(20);             
  }
  for (pos = 75; pos >= 0; pos -= 1) { 
    myservo2.write(pos); 
    delay(20);             
  }
  TurnOFFA();
  // Drops disc 6
  delay(1000);
  // Initiates picking sequence for disc 16
  for (pos = 0; pos <= 90; pos += 1) { 
    myservo2.write(pos); 
    delay(20);            
  }
  myservo4.write(45);
  myservo1.write(150);
  myservo1.write(0); 
  myservo2.write(120); 
  myservo3.write(120);  
  myservo4.write(60);
  delay(1000);
  for (pos = 120; pos >= 80; pos -= 1) { 
    myservo2.write(pos);
    delay(20);             
  }
  myservo4.write(70);  
  for (pos = 80; pos >= 72; pos -= 1) { 
    myservo2.write(pos);
    delay(20);             
  }
  for (pos = 70; pos >= 60; pos -= 1) { 
    myservo4.write(pos);
    delay(20);              
  }
  myservo2.write(90);
  myservo4.write(68);
  for (pos = 120; pos <= 155; pos += 1) { 
    myservo3.write(pos); 
    delay(20);            
  }
  delay(1000);
  TurnMotorA();
  for (pos = 90; pos >= 70; pos -= 1) { 
    myservo2.write(pos); 
    delay(20);             
  }
  delay(1000);
  
  for (pos = 70; pos <= 80; pos += 1) { 
    myservo2.write(pos); 
    delay(20);            
  }
  for (pos = 80; pos <= 100; pos += 1) { 
    myservo2.write(pos); 
    delay(20);            
  }
  // Completes picking the disc and initiates dropping sequence
  for (pos = 150; pos >= 120; pos -= 1) { 
    myservo3.write(pos); 
    delay(20);             
  }
  for (pos = 100; pos <= 120; pos += 1) { 
    myservo2.write(pos); 
    delay(20);            
  }  
  for (pos = 30; pos <= 111; pos += 1) { 
    myservo1.write(pos);
    delay(20);              
  }
  for (pos = 120; pos >= 75; pos -= 1) {
    myservo2.write(pos); 
    delay(20);           
  }
  for (pos = 120; pos >= 100; pos -= 1) { 
    myservo3.write(pos);
    delay(20);             
  }
  for (pos =60; pos <=117; pos += 1) { 
    myservo4.write(pos); 
    delay(20);             
  }
  for (pos = 75; pos >= 0; pos -= 1) { 
    myservo2.write(pos); 
    delay(20);             
  }
  TurnOFFA();
  // Drops disc 7
  delay(1000);
  // Initiates picking sequence for disc 17
  for (pos = 0; pos <= 90; pos += 1) { 
    myservo2.write(pos); 
    delay(20);            
  }
  myservo4.write(45);
  myservo1.write(150);
  // Move backwards my 5 cm
  myStepper.moveTo(-114);
  myStepper.runToPosition();
  PickWhite();
  // Completes picking the disc and initiates dropping sequence
  for (pos = 150; pos >= 120; pos -= 1) { 
    myservo3.write(pos); 
    delay(20);            
  }
  for (pos = 30; pos <= 146; pos += 1) { 
    myservo1.write(pos);
    delay(20);             
  } 
  for (pos = 90; pos >= 75; pos -= 1) {
    myservo2.write(pos); 
    delay(20);            
  }
  for (pos = 120; pos >= 80; pos -= 1) { 
    myservo3.write(pos);
    delay(20);             
  }
  for (pos =60; pos <=86; pos += 1) { 
    myservo4.write(pos); 
    delay(20);             
  }
  for (pos = 75; pos >= 0; pos -= 1) { 
    myservo2.write(pos); 
    delay(20);            
  }
  TurnOFFA();
  // Drops disc 1  
  delay(1000);
  // Initiates picking sequence for disc 18
  for (pos = 0; pos <= 90; pos += 1) { 
    myservo2.write(pos); 
    delay(20);            
  }
  myservo4.write(45);
  myservo1.write(150);
  myservo1.write(0); // Declaring initial positions of servos
  myservo2.write(120); 
  myservo3.write(120);  
  myservo4.write(60);
  delay(1000);
  for (pos = 120; pos >= 80; pos -= 1) { 
    myservo2.write(pos);
    delay(20);             
  }
  myservo4.write(70);  
  for (pos = 80; pos >= 70; pos -= 1) { 
    myservo2.write(pos);
    delay(20);             
  }
  for (pos = 70; pos >= 50; pos -= 1) { 
    myservo4.write(pos);
    delay(20);              
  }
  myservo2.write(90);
  myservo4.write(70);
  for (pos = 120; pos <= 155; pos += 1) { 
    myservo3.write(pos); 
    delay(20);            
  }
  delay(1000);
  TurnMotorA();
  for (pos = 90; pos >= 70; pos -= 1) { 
    myservo2.write(pos); 
    delay(20);             
  }
  delay(1000);
  
  for (pos = 70; pos <= 80; pos += 1) { 
    myservo2.write(pos); 
    delay(20);            
  }
  for (pos = 80; pos <= 100; pos += 1) { 
    myservo2.write(pos); 
    delay(20);            
  }
  // Completes picking the disc and initiates dropping sequence
  for (pos = 150; pos >= 120; pos -= 1) { 
    myservo3.write(pos); 
    delay(20);             
  }
  for (pos = 100; pos <= 120; pos += 1) { 
    myservo2.write(pos); 
    delay(20);            
  }
  for (pos = 0; pos <= 129; pos += 1) {
    myservo1.write(pos);
    delay(20);             
  }
  for (pos = 120; pos >= 75; pos -= 1) { 
    myservo2.write(pos);
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
void loop() { 
}

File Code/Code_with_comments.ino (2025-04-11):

#include <AccelStepper.h>
#include <Servo.h>

// Define stepper motor control pins
const int dirPin = 26;
const int stepPin = 3;
#define motorInterfaceType 1

// Create stepper motor instance
AccelStepper myStepper(motorInterfaceType, stepPin, dirPin);

// Define servo motors
Servo myservo1, myservo2, myservo3, myservo4;
int pos = 0; // Variable to store servo position

// Define vacuum motor control pins
int in1 = 9;
int in2 = 46;

// Function to turn on the vacuum pump
void TurnMotorA() {
  digitalWrite(in1, HIGH);
  digitalWrite(in2, LOW);
}

// Function to turn off the vacuum pump
void TurnOFFA() {
  digitalWrite(in1, LOW);
  digitalWrite(in2, LOW);
}

// Function to pick a white disc
void PickWhite() {
  myservo1.write(30);
  myservo4.write(59);
  myservo2.write(85);

  for (pos = 90; pos <= 150; pos++) {
    myservo3.write(pos);
    delay(20);
  }

  delay(1000);
  TurnMotorA();

  for (pos = 85; pos >= 70; pos--) {
    myservo2.write(pos);
    delay(20);
  }

  delay(1000);

  for (pos = 70; pos <= 90; pos++) {
    myservo2.write(pos);
    delay(20);
  }
}

// Function to pick a black disc
void PickBlack() {
  myservo2.write(100);
  myservo1.write(0);
  myservo4.write(68);

  for (pos = 90; pos <= 155; pos++) {
    myservo3.write(pos);
    delay(20);
  }

  for (pos = 100; pos >= 90; pos--) {
    myservo2.write(pos);
    delay(20);
  }

  delay(1000);
  TurnMotorA();

  for (pos = 90; pos >= 70; pos--) {
    myservo2.write(pos);
    delay(20);
  }

  delay(1000);

  for (pos = 70; pos <= 80; pos++) {
    myservo2.write(pos);
    delay(20);
  }

  for (pos = 80; pos <= 100; pos++) {
    myservo2.write(pos);
    delay(20);
  }
}

// Setup function
void setup() {
  // Setup motor control pins
  pinMode(in1, OUTPUT);
  pinMode(in2, OUTPUT);

  // Initialize stepper motor
  myStepper.setMaxSpeed(1000);
  myStepper.setAcceleration(50);
  myStepper.setSpeed(200);

  // Attach servo motors to their respective pins
  myservo1.attach(5);
  myservo2.attach(6);
  myservo3.attach(10);
  myservo4.attach(11);

  // Set initial positions for the servo motors
  myservo1.write(150);
  myservo2.write(90);
  myservo3.write(90);
  myservo4.write(45);

  // Move stepper to starting position
  myStepper.moveTo(-218);
  myStepper.runToPosition();
  TurnMotorA();
  delay(1000);
  TurnOFFA();

  Serial.begin(9600);

  // --- SEQUENCE STARTS HERE ---
  // Call your pick and drop sequences from here.
  // Modularize your code from the original if needed to keep this function clean.

  // For example:
  // ExecutePickDropSequence(WHITE);
  // MoveBotBackward(5);
  // ExecutePickDropSequence(BLACK);
  // ...
  // Since the original code had many repetitive blocks, consider moving those into
  // reusable functions if needed.

  // At the end, return the stepper to original position
  myStepper.moveTo(0);
  myStepper.runToPosition();
}

// Loop function (not used here)
void loop() {
  // Empty since all actions are in setup()
}

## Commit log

2025-04-11 Create a
    This folder contains the 3D SOLIDWORKS models of part files that are ensambled together to create an assembly of the CarromBOT which is the Assembly.SLDASM file. Here the 7 files:
    *Body
    *Hand Base
    *Hand Base_2
    *HAnd Tip
    *Hand Mid
    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
2025-04-11 Add files via upload
    The arduino code that has been used for the project.
